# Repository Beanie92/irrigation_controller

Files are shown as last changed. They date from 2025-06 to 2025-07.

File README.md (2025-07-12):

# Hydr8: Irrigation Controller



An ESP32-C6 based irrigation controller with web interface, manual controls, and flexible scheduling.

## Features

- **WiFi & Web UI**: Configure and control the system from any web browser.
- **Manual Control**: Use the physical rotary encoder for on-the-spot adjustments.
- **Flexible Scheduling**: Set up to three different irrigation cycles (A, B, C) with custom start times, zone durations, and active days.
- **NTP Time Sync**: Automatically keeps time updated from the internet.
- **IPS Display**: A clear color display shows system status and menus with auto dimming.
- **8-Channel Control**: Manages a pump and up to seven irrigation zones.
- **Fully Offline Mode**: Operates completely without a WiFi connection, with all features accessible via the device interface.

## Screenshots

### Web Interface



### On-Device UI

Screenshot from 2025-06-29 21-27-22

## Hardware

- **CAD Files**: [View on OnShape](https://cad.onshape.com/documents/08bfc36dcbbf2398b4b87e4d/w/2dae12507b7940b517cf4320/e/530747a0889b15aeda69d576)
- **Electronics** (sourced from [robotics.org.za](https://www.robotics.org.za/)):
  - FireBeetle 2 ESP32-C6 IoT Development Board
  - Wave 2 Inch IPS Display 320x240 SPI ST7789
  - Rotary Encoder Module - Breadboard Ready
  - 4 x 2-Channel Relay Module Opto Isolated 3.3V & 5V Logic 10A Load
  - Battery LiPo 5000mAh 3.7V
  - WCS1500 Hall 35A Current Sensor

## Firmware

The firmware is built using the Arduino framework for the ESP32. It includes a web server, a full UI for the display, and handles all the logic for scheduling and manual control.

For detailed instructions on how to set up the development environment, configure the firmware, and upload it to the ESP32, please see the [firmware README](./firmware/README.md).

## Future Work

- **Smarter Current Monitoring**: Implement logic to use the WCS1800 current sensor to detect pump failures, dry running, or other anomalies, and provide alerts or shut down the system automatically.

## Gallery

Build before the mess of wires:



Build after the mess of wires:



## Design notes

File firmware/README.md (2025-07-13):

# Irrigation Controller Firmware

ESP32-C6 based irrigation controller with WiFi connectivity and NTP time synchronization.

## Features

- **WiFi Connectivity**: Automatic connection to saved WiFi networks
- **NTP Time Synchronization**: Automatic time sync from internet time servers
- **Web Server Interface**: Configure settings, view status, and control zones/cycles via a web browser.
- **Manual Zone Control**: Control individual irrigation zones via rotary encoder interface or web UI.
- **Cycle Scheduling**: Three programmable irrigation schedules (A, B, C) configurable via device UI or web UI.
- **TFT Display**: 240x320 color display with intuitive menu system.
- **Relay Control**: 8-channel relay control (1 pump + 7 zones).
- **Fully Offline Mode**: Operates completely without a WiFi connection, with all features accessible via the device interface.

## Hardware Requirements

- ESP32-C6 development board (DFRobot Beetle ESP32-C6)
- ST7789 240x320 TFT display
- KY-040 rotary encoder with button
- 4 x 2-channel relay module
- Power supply suitable for your relay/pump requirements

## Pin Configuration

### Display (ST7789)
- DC: Pin 2
- CS: Pin 6
- RST: Pin 3

### Rotary Encoder (KY-040)
- CLK: Pin 4
- DT: Pin 7
- SW: Pin 16

### Relays
- Relay 0 (Pump): Pin 19
- Relay 1 (Zone 1): Pin 20
- Relay 2 (Zone 2): Pin 17
- Relay 3 (Zone 3): Pin 18
- Relay 4 (Zone 4): Pin 15
- Relay 5 (Zone 5): Pin 21
- Relay 6 (Zone 6): Pin 8
- Relay 7 (Zone 7): Pin 14

### Current Sensor
-  Anlog Read: Pin 1

## WiFi Setup

The system uses **WiFiManager** with a captive portal for easy WiFi configuration - **WiFi setup is completely optional!**

### Optional WiFi Setup (User-Controlled)

WiFi is now configured through the Settings menu - the system boots directly to the main menu without any WiFi delays.

1. **Navigate to Settings** from the main menu using the rotary encoder
2. **Select "WiFi Setup"** to start the configuration process
3. **The device creates a hotspot**:
   - **Network Name**: `IrrigationController`
   - **Password**: `irrigation123`
4. **Connect your phone/laptop** to the `IrrigationController` network
5. **Open a web browser** - you'll be automatically redirected to the config page
   - If not redirected, go to: `192.168.4.1`
6. **Select your WiFi network** from the list and enter your password
7. **Click Save** - the device will connect to your WiFi and sync time

### Status Display

The device display will show:
- **"WiFi Setup - Connecting..."** when attempting connection
- **"WiFi Setup Required"** with step-by-step instructions when captive portal is active
- **"WiFi Connected!"** with network details when successful
- **"WiFi Setup Timed Out"** if configuration takes too long (3 minutes)

### Reconfiguring WiFi

To change WiFi settings:
1. Use the "WiFi Reset" option in the Settings menu on the device.
2. The captive portal will automatically start again on the next "WiFi Setup" attempt or if the device cannot connect to a previously saved network.

### Troubleshooting WiFi

- **Portal not appearing**: Ensure you're connected to `IrrigationController` network
- **Can't connect to portal**: Try browsing to `192.168.4.1` manually
- **WiFi keeps failing**: Check 2.4GHz network (ESP32 doesn't support 5GHz)
- **Timeout issues**: Portal times out after 3 minutes - restart device to try again

## Time Configuration

The system automatically synchronizes time with NTP servers when WiFi is connected:

- **NTP Server**: pool.ntp.org
- **Timezone**: GMT+2 (Botswana/South Africa)
- **Sync Interval**: Every hour
- **Fallback**: Software clock when WiFi unavailable

To change timezone, modify these values in the code:
```cpp
const long gmtOffset_sec = 7200;     // GMT+2 (adjust as needed)
const int daylightOffset_sec = 0;    // Daylight saving offset
```

## Web Server Interface

Once the ESP32 is connected to your WiFi network, you can access the web interface by navigating to its IP address in a web browser. The IP address is displayed on the device's screen after a successful WiFi connection and also printed to the Serial Monitor.

The web interface allows you to:
- View current system time and relay (zone) statuses.
- Manually set the system date and time.
- Manually start individual zones for a specified duration.
- Stop all currently running irrigation activity.
- View and configure all three irrigation cycles (A, B, C):
    - Enable/disable cycles.
    - Set start time (hour, minute).
    - Set inter-zone delay.
    - Select active days of the week.
    - Configure run durations for each of the 7 zones.
- Manually start a configured cycle.

## Menu System

### Main Menu
- **Manual Run**: Start individual zones manually
- **Settings**: Access system configuration options
- **Set Cycle Start**: Configure cycle start times
- **Cycle A/B/C**: Configure automated irrigation cycles

### Settings Submenu
- **WiFi Setup**: Launch captive portal for WiFi configuration
- **Set Time Manually**: Configure date/time manually (when NTP unavailable)
- **WiFi Reset**: Clear saved WiFi credentials
- **System Info**: View hardware and network status
- **Back to Main Menu**: Return to main menu

### Navigation
- **Rotate Encoder**: Navigate through options
- **Press Button**: Select/confirm option
- **Long Press**: Cancel/return to previous menu

## Programming Irrigation Schedules

Each cycle (A, B, C) can be configured with:
- **Zone Durations**: Individual run times for each zone (0-120 minutes)
- **Inter-zone Delay**: Pause between zones (0-30 minutes)
- **Start Time**: When the cycle should begin
- **Active Days**: Which days of the week to run

## Troubleshooting

### WiFi Connection Issues
1. Check SSID and password are correct
2. Ensure 2.4GHz network (ESP32 doesn't support 5GHz)
3. Check signal strength in installation location
4. Monitor serial output for connection status

### Time Sync Issues
1. Verify WiFi connection is working
2. Check internet connectivity
3. Firewall may be blocking NTP (port 123)
4. Try different NTP server if needed

### Display Issues
1. Check all display connections
2. Verify power supply voltage
3. Check SPI pin assignments match your hardware

## Development

### Arduino IDE Setup
1. Install ESP32 board package
2. Select "ESP32C6 Dev Module" as board
3. Install required libraries via the Arduino Library Manager:
   - **Adafruit GFX Library**: A dependency for the display driver.
   - **ArduinoJson**: Used for handling JSON data for configuration.
   - **ESPAsyncWebServer**: Powers the web interface. **Note**: This library seems to work reliably with version 3.7.1.
   - **LittleFS**: For file system storage.
   - **WiFiManager** by tzapu: For easy WiFi configuration.

### Web UI Development

The web interface assets (HTML, JavaScript) are located in the `web-ui` directory. This project uses `webpack` to bundle and optimize the assets.

**Prerequisites:**
- [Node.js and npm](https://nodejs.org/en/download/)

**Workflow:**

1.  **Navigate to the UI directory:**
    ```bash
    cd web-ui
    ```

2.  **Install dependencies** (only needs to be done once):
    ```bash
    npm install
    ```

3.  **Make changes** to the source files located in `web-ui/src` and `web-ui/plot.js`.

4.  **Build the web assets:**
    ```bash
    npm run build
    ```
    This command will:
    - Bundle the JavaScript and HTML files.
    - Copy static assets.
    - Create Gzip-compressed versions of the assets (`.gz`).
    - Place all the final files into the `firmware/data` directory.

5.  **Upload to ESP32:**
    - After building, use the **Tools > ESP32 Sketch Data Upload** option in the Arduino IDE. This will upload the contents of the `data` directory to the device's LittleFS filesystem.

The firmware is configured to automatically serve the gzipped assets, which reduces storage space and improves loading times.

### Serial Debug Output
Enable debug output by setting:
```cpp
#define DEBUG_ENABLED true
```

Connect serial monitor at 115200 baud to see detailed system information.

## Safety Notes

- Always verify relay wiring before connecting pumps/valves
- Use appropriate fuses and circuit protection
- Test manual operation before setting up automated cycles
- Ensure adequate power supply for your specific hardware
- Consider using contactors for high-power pumps

## License

This project is open source. Use and modify as needed for your irrigation requirements.

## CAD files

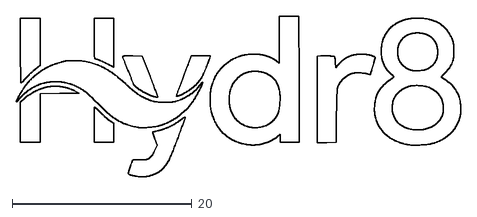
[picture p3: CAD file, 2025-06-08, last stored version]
logo (1).dxf
49.5 x 17.9

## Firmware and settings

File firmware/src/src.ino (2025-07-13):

#include <Arduino.h>
#include "st7789_dma_driver.h" // Replaced DFRobot_GDL.h
#include "styling.h"
#include "CustomCanvas.h"
#include "ui_components.h"
#include "web_server.h" // Include the web server header
#include "wifi_manager.h" // Include the new WiFi manager
#include "config_manager.h" // Include the configuration manager
#include "current_sensor.h" // Include the current sensor header
#include "battery.h" // Include the battery header
#include "logo.h"
#include <LittleFS.h>

// -----------------------------------------------------------------------------
//                           DEBUG CONFIGURATION
// -----------------------------------------------------------------------------
#define DEBUG_ENABLED false  // Set to false to disable all debug logging

#if DEBUG_ENABLED
  #define DEBUG_PRINT(x) Serial.print(x)
  #define DEBUG_PRINTLN(x) Serial.println(x)
  #define DEBUG_PRINTF(format, ...) Serial.printf(format, ##__VA_ARGS__)
#else
  #define DEBUG_PRINT(x)
  #define DEBUG_PRINTLN(x)
  #define DEBUG_PRINTF(format, ...)
#endif

// -----------------------------------------------------------------------------
//                    Rotary Encoder Inputs / Global Variables
// -----------------------------------------------------------------------------
static const int pinA   = 4;   // KY-040 CLK
static const int pinB   = 7;   // KY-040 DT
static const int button = 16;  // KY-040 SW (with internal pull-up)

volatile long encoderValue = 0;
volatile bool encoderMoved = false;
volatile bool encoder_button_pressed = false;

// For button software debounce:
unsigned long lastButtonPressTime = 0;
const unsigned long buttonDebounce = 200; // milliseconds

// -----------------------------------------------------------------------------
//                        Relay Pins / Configuration
// -----------------------------------------------------------------------------
const int NUM_RELAYS = 8; // Made non-static for web_server.h extern
// Relay 0 is dedicated to the borehole pump;
// Relays 1..7 are the irrigation zones.
static const int relayPins[NUM_RELAYS] = {19, 20, 17, 18, 15, 21, 8, 14}; 
bool relayStates[NUM_RELAYS] = {false, false, false, false, false, false, false, false};

static const int PUMP_IDX = 0;   // borehole pump
// ZONE_COUNT is now defined in ui_components.h

// -----------------------------------------------------------------------------
//                           Display Pins / Driver
// -----------------------------------------------------------------------------
#define TFT_DC   2
#define TFT_CS   6
#define TFT_RST  3
#define TFT_BL   5 // Backlight control pin for dimming

CustomCanvas canvas(320, 240);

// Relay labels (index 0 is the pump)
const char* relayLabels[NUM_RELAYS] = {
  "Pump (auto)", // index 0; not displayed in manual-run menu
};

// -----------------------------------------------------------------------------
//                           Screen Dimming
// -----------------------------------------------------------------------------
unsigned long lastActivityTime = 0;
const unsigned long inactivityTimeout = 30000; // 30 seconds
bool isScreenDimmed = false;
volatile bool uiDirty = true; // Flag to trigger UI redraw

// -----------------------------------------------------------------------------
//                        Battery Level
// -----------------------------------------------------------------------------
int batteryLevel = 100; // Default to 100 on boot

// -----------------------------------------------------------------------------
//                        Current Sensing Pin / Configuration
// -----------------------------------------------------------------------------
// Current sensor is now handled in current_sensor.cpp


// -----------------------------------------------------------------------------
//                           Menu and Cycle States
// -----------------------------------------------------------------------------
// ActiveOperationType is now defined in ui_components.h

enum UIState {
  STATE_BOOTING,
  STATE_MAIN_MENU,
  STATE_MANUAL_RUN,
  STATE_CYCLES_MENU,
  STATE_CYCLE_A_MENU,
  STATE_CYCLE_B_MENU,
  STATE_CYCLE_C_MENU,
  STATE_SETTINGS,
  STATE_SET_SYSTEM_TIME,
  STATE_WIFI_SETUP_LAUNCHER, // Renamed from STATE_WIFI_SETUP
  STATE_WIFI_RESET,
  STATE_SYSTEM_INFO,
  STATE_RESTART_DEVICE,
  STATE_PROG_A,
  STATE_PROG_B,
  STATE_PROG_C,
  STATE_RUNNING_ZONE,
  STATE_CYCLE_RUNNING,
  STATE_TEST_MODE
};

UIState currentState = STATE_BOOTING;
const int UI_STATE_STACK_SIZE = 10;
UIState uiStateStack[UI_STATE_STACK_SIZE];
int uiStateStackPtr = -1;
ActiveOperationType currentOperation = OP_NONE; // Track what kind of operation is active

// Main Menu Items
static const int MAIN_MENU_ITEMS = 4; 
const char* mainMenuLabels[MAIN_MENU_ITEMS] = {
  "Manual Run",
  "Cycles", // New submenu
  "Test Mode",
  "Settings"
};
int selectedMainMenuIndex = 0; 

// Cycles Menu Items (lists Cycle A, B, C)
static const int CYCLES_MENU_ITEMS = 3; // A, B, C
const char* cyclesMenuLabels[CYCLES_MENU_ITEMS] = {
  "Cycle A",
  "Cycle B",
  "Cycle C"
};
int selectedCyclesMenuIndex = 0;

// Individual Cycle Sub-Menu Items (Run Now, Configure)
static const int CYCLE_SUB_MENU_ITEMS = 2; // Run Now, Configure
const char* cycleSubMenuLabels[CYCLE_SUB_MENU_ITEMS] = {
  "Run Now",
  "Configure"
};
int selectedCycleSubMenuIndex = 0;
ScrollableList cycleSubMenuScrollList;

// Settings Menu Items
static const int SETTINGS_MENU_ITEMS = 5;
const char* settingsMenuLabels[SETTINGS_MENU_ITEMS] = {
  "WiFi Setup",
  "Set Time Manually",
  "WiFi Reset",
  "System Info",
  "Restart Device"
};
int selectedSettingsMenuIndex = 0;
ScrollableList settingsMenuScrollList;

// WiFi Setup Launcher Menu Items
static const int WIFI_SETUP_LAUNCHER_MENU_ITEMS = 2;
const char* wifiSetupLauncherMenuLabels[WIFI_SETUP_LAUNCHER_MENU_ITEMS] = {
  "Start WiFi Portal",
  "Back"
};
int selectedWiFiSetupLauncherIndex = 0;
ScrollableList wifiSetupLauncherScrollList;

// Manual Run zone index: 0..6 => zone = index+1
int selectedManualZoneIndex = 0;
// Made non-static to be accessible from web_server.cpp
int selectedManualDuration = 5;  // Default 5 minutes 
bool selectingDuration = false;  // Whether we're selecting duration or zone
ScrollableList manualRunScrollList;
const char* zoneNamePointers[ZONE_COUNT]; // Array of pointers for scrollable list

// Cycle Config zone selection
char cycleZoneDisplayStrings[ZONE_COUNT][50];
const char* cycleZoneDisplayPointers[ZONE_COUNT];
int selectedCycleZoneIndex = 0; // Used by all program config screens
bool editingCycleField = false; // Are we editing a field in the cycle config?

// -----------------------------------------------------------------------------
//                           Zone Timer Variables
// -----------------------------------------------------------------------------
unsigned long zoneStartTime = 0;        // When current zone started
unsigned long zoneDuration = 0;         // Duration for current zone in milliseconds
int currentRunningZone = -1;            // Which zone is currently running (-1 = none)
bool isTimedRun = false;                 // Whether this is a timed run or manual indefinite run
int currentRunningCycle = -1;         // Which cycle is currently running (-1 = none, 0=A, 1=B, 2=C)
int currentCycleZoneIndex = -1;       // Current zone index within a running cycle
unsigned long cycleZoneStartTime = 0; // When current cycle zone started
unsigned long cycleInterZoneDelayStartTime = 0; // When inter-zone delay started
bool inInterZoneDelay = false;          // Flag for inter-zone delay

// -----------------------------------------------------------------------------
//                           Test Mode Variables
// -----------------------------------------------------------------------------
bool testModeActive = false;
int currentTestRelay = 0;           // 0-7: 0=pump, 1-7=zones
unsigned long testModeStartTime = 0;
const unsigned long TEST_INTERVAL = 5000; // 5 seconds per relay

// -----------------------------------------------------------------------------
//                  Time-Keeping (Software Simulation)
// -----------------------------------------------------------------------------
SystemDateTime currentDateTime = {2023, 1, 1, 8, 0, 0}; // Example start date/time
unsigned long lastSecondUpdate = 0; // track millis() to increment seconds

void incrementOneSecond() {
  // Very simplistic approach: just add 1 second, then handle minute/hour/day wrap
  currentDateTime.second++;
  if (currentDateTime.second >= 60) {
    currentDateTime.second = 0;
    currentDateTime.minute++;
    if (currentDateTime.minute >= 60) {
      currentDateTime.minute = 0;
      currentDateTime.hour++;
      if (currentDateTime.hour >= 24) {
        currentDateTime.hour = 0;
        currentDateTime.day++;
        // Very naive day wrap (assumes 30 days). In real code, handle months properly.
        if (currentDateTime.day > 30) {
          currentDateTime.day = 1;
          currentDateTime.month++;
          if (currentDateTime.month > 12) {
            currentDateTime.month = 1;
            currentDateTime.year++;
          }
        }
      }
    }
  }
}

// -----------------------------------------------------------------------------
//                 Cycle Config
// -----------------------------------------------------------------------------
// TimeOfDay and CycleConfig structs are now defined in ui_components.h

CycleConfig* cycles[] = {&systemConfig.cycles[0], &systemConfig.cycles[1], &systemConfig.cycles[2]};
const int NUM_CYCLES = 3; // Made non-static for web_server.h extern

// -----------------------------------------------------------------------------
//                Sub-indexes and helpers for editing fields
// -----------------------------------------------------------------------------
static int timeEditFieldIndex = 0;    // 0=year,1=month,2=day,3=hour,4=minute,5=second
static bool editingTimeField = false;
static int cycleEditFieldIndex = 0; // 0=enabled, 1=hour, 2=minute, 3=interZoneDelay, 4-10=days, 11-17=zone durations
static int zoneEditScrollOffset = 0; // For scrolling through zones in cycle config

// Ranges for system time fields (simple example)
#define MIN_YEAR  2020
#define MAX_YEAR  2050


// Global instance for main menu
ScrollableList mainMenuScrollList;
ScrollableList cyclesMenuScrollList;
ScrollableList cycleZonesScrollList; // For zone durations in cycle config
ScrollableList setTimeScrollList;

// -----------------------------------------------------------------------------
//                           Forward Declarations
// -----------------------------------------------------------------------------
void updateScreen();
void render();
void isrPinA();
void handleEncoderMovement();
void handleButtonPress();

void drawLogo();
void drawMainMenu();
void drawCyclesMenu();
void drawCycleSubMenu(const char* label);
void navigateTo(UIState newState, bool isNavigatingBack = false);
void goBack();

void updateSoftwareClock();
DayOfWeek getCurrentDayOfWeek();

// Manual Run
void drawManualRunMenu();
void drawRunningZoneMenu();
void startManualZone(int zoneIdx);
void stopAllActivity(); // Renamed from stopZone

// Set System Time
void drawSetSystemTimeMenu();
void handleSetSystemTimeEncoder(long diff);
void handleSetSystemTimeButton();

// Program A/B/C
void drawCycleConfigMenu(const char* label, CycleConfig& cfg);
void handleCycleEditEncoder(long diff, CycleConfig &cfg, const char* progLabel);
void handleCycleEditButton(CycleConfig &cfg, UIState thisState, const char* progLabel);
void startCycleRun(int cycleIndex, ActiveOperationType type);
void updateCycleRun();
void drawCycleRunningMenu();

// Settings menu functions
void drawSettingsMenu();
void drawWiFiResetMenu();
void drawSystemInfoMenu();
void drawWiFiSetupLauncherMenu(); // Renamed from drawWiFiSetupMenu
void drawRestartDeviceMenu();

// Test Mode functions
void startTestMode();
void updateTestMode();
void drawTestModeMenu();
void stopTestMode();

// -----------------------------------------------------------------------------
//                              RELAY CONTROL
// -----------------------------------------------------------------------------
bool isAnyZoneActive() {
  for (int i = 1; i < NUM_RELAYS; i++) {
    if (relayStates[i]) {
      return true;
    }
  }
  return false;
}

void setPumpState(bool on) {
  if (on) {
    // Only turn the pump on if at least one zone is active.
    if (isAnyZoneActive()) {
      if (!relayStates[PUMP_IDX]) {
        DEBUG_PRINTF("Activating pump relay (pin %d)\n", relayPins[PUMP_IDX]);
        relayStates[PUMP_IDX] = true;
        digitalWrite(relayPins[PUMP_IDX], HIGH);
      }
    } else {
      DEBUG_PRINTLN("PUMP SAFETY: Pump activation prevented. No zones are active.");
      // Ensure pump is off if we get here, just in case.
      if (relayStates[PUMP_IDX]) {
        relayStates[PUMP_IDX] = false;
        digitalWrite(relayPins[PUMP_IDX], LOW);
      }
    }
  } else {
    // Turn the pump off.
    if (relayStates[PUMP_IDX]) {
      DEBUG_PRINTF("Deactivating pump on pin %d\n", relayPins[PUMP_IDX]);
      relayStates[PUMP_IDX] = false;
      digitalWrite(relayPins[PUMP_IDX], LOW);
    }
  }
}
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
void loop() {
  // --------------------- SAFETY CHECK ---------------------
  // Ensure the pump is never running if no zones are active.
  // This is a failsafe in case of a logic error elsewhere.
  if (relayStates[PUMP_IDX] && !isAnyZoneActive()) {
    DEBUG_PRINTLN("!!! PUMP SAFETY ALERT !!! Pump was on without an active zone. Forcing OFF.");
    setPumpState(false);
  }
  // --------------------------------------------------------

  // Handle WiFi and NTP updates
  wifi_manager_handle();

  // --- DEBUG: Read and print current sensor value ---
  static unsigned long lastCurrentRead = 0;
  if (millis() - lastCurrentRead > 2000) { // Read every 2 seconds
    float current = read_wcs1800_current();
    DEBUG_PRINTF("[CURRENT] Reading: %.5f A\n", current);
    lastCurrentRead = millis();
  }
  // ----------------------------------------------------

  // Update the current history
  update_current_history();

  // --- Read battery level ---
  static unsigned long lastBatteryRead = 0;
  if (millis() - lastBatteryRead > 5000) { // Read every 5 seconds
    batteryLevel = read_battery_level();
    DEBUG_PRINTF("[BATTERY] Level: %d%%\n", batteryLevel);
    lastBatteryRead = millis();
    uiDirty = true; // Redraw header with new level
  }
  // ----------------------------------------------------
  
  if (encoder_button_pressed && currentState == STATE_BOOTING) {
    wifi_manager_cancel_connection();
    encoder_button_pressed = false; // Reset flag
  }

  if (wifi_manager_is_connecting() == false && currentState == STATE_BOOTING) {
    navigateTo(STATE_MAIN_MENU);
  }

  // Update time - use NTP if available, otherwise software clock
  if (wifi_manager_is_time_synced()) {
    wifi_manager_update_system_time(currentDateTime); // Update our time structure from system time
  } else {
    updateSoftwareClock(); // Fallback to software clock
  }
  
  handleEncoderMovement();
  handleButtonPress();

  // Render the UI if needed
  render();

  // Handle screen dimming
  if (!isScreenDimmed && (millis() - lastActivityTime > inactivityTimeout)) {
    isScreenDimmed = true;
    st7789_set_backlight(false); // Dim the screen using the driver
    DEBUG_PRINTLN("Screen dimmed due to inactivity.");
  }

  // Check for scheduled cycles if no other operation is active
  if (currentOperation == OP_NONE) {
    DayOfWeek currentDay = getCurrentDayOfWeek();
    for (int i = 0; i < NUM_CYCLES; i++) {
      CycleConfig* cfg = cycles[i];
      if (cfg->enabled && (cfg->daysActive & currentDay) &&
          currentDateTime.hour == cfg->startTime.hour &&
          currentDateTime.minute == cfg->startTime.minute &&
          currentDateTime.second == 0) { // Trigger at the start of the minute
        DEBUG_PRINTF("Scheduled cycle %s triggered!\n", cfg->name);
        startCycleRun(i, OP_SCHEDULED_CYCLE);
        break; // Only one cycle can start per second
      }
    }
  }

  // Additional logic for running states if needed
  if (currentState == STATE_RUNNING_ZONE) {
    static unsigned long lastDisplayUpdate = 0;
    if (millis() - lastDisplayUpdate > 5000) {
      lastDisplayUpdate = millis();
      uiDirty = true;
    }
    
    if (isTimedRun && zoneDuration > 0) {
      unsigned long elapsed = millis() - zoneStartTime;
      if (elapsed >= zoneDuration) {
        DEBUG_PRINTLN("Zone timer expired - stopping zone");
        stopAllActivity();
        navigateTo(STATE_MAIN_MENU);
      }
    }
  } else if (currentState == STATE_CYCLE_RUNNING) {
    updateCycleRun();
  } else if (currentState == STATE_TEST_MODE && testModeActive) {
    updateTestMode();
  }
}

// -----------------------------------------------------------------------------
//                        INTERRUPT SERVICE ROUTINE
// -----------------------------------------------------------------------------
void IRAM_ATTR isrPinA() {
  bool A = digitalRead(pinA);
  bool B = digitalRead(pinB);
  if (A == B) {
    encoderValue = encoderValue - 1;
  } else {
    encoderValue = encoderValue + 1;
  }
  encoderMoved = true;
  uiDirty = true;
}

// -----------------------------------------------------------------------------
//                         ENCODER & BUTTON HANDLERS
// -----------------------------------------------------------------------------
static long lastEncoderPosition = 0;
void handleEncoderMovement() {
  if (!encoderMoved) return;

  noInterrupts();
  long newVal = encoderValue;
  encoderMoved = false;
  interrupts();

  long diff = newVal - lastEncoderPosition;
  lastEncoderPosition = newVal;
  if (diff == 0) return;

  lastActivityTime = millis();
  if (isScreenDimmed) {
    st7789_set_backlight(true); // Full brightness
    isScreenDimmed = false;
    uiDirty = true; // Redraw the screen
    DEBUG_PRINTLN("Screen woken up by encoder movement.");
    return; // Ignore the first input
  }
  uiDirty = true;

  DEBUG_PRINTF("Encoder moved: diff=%ld, state=%d\n", diff, currentState);

  switch (currentState) {
    case STATE_MAIN_MENU:
      handleScrollableListInput(mainMenuScrollList, diff);
      break;

    case STATE_CYCLES_MENU:
      handleScrollableListInput(cyclesMenuScrollList, diff);
      break;

    case STATE_CYCLE_A_MENU:
    case STATE_CYCLE_B_MENU:
    case STATE_CYCLE_C_MENU:
      handleScrollableListInput(cycleSubMenuScrollList, diff);
      break;

    case STATE_MANUAL_RUN:
      if (selectingDuration) {
        selectedManualDuration += diff;
        if (selectedManualDuration < 1) selectedManualDuration = 120;
        if (selectedManualDuration > 120) selectedManualDuration = 1;
        DEBUG_PRINTF("Manual run duration selection: %d minutes\n", selectedManualDuration);
      } else {
        handleScrollableListInput(manualRunScrollList, diff);
      }
      break;

    case STATE_SETTINGS:
      handleScrollableListInput(settingsMenuScrollList, diff);
      break;

    case STATE_WIFI_SETUP_LAUNCHER:
      handleScrollableListInput(wifiSetupLauncherScrollList, diff);
      break;

    case STATE_SET_SYSTEM_TIME:
      handleSetSystemTimeEncoder(diff);
      break;

    case STATE_PROG_A:
      handleCycleEditEncoder(diff, systemConfig.cycles[0], "Cycle A");
      break;

    case STATE_PROG_B:
      handleCycleEditEncoder(diff, systemConfig.cycles[1], "Cycle B");
      break;

    case STATE_PROG_C:
      handleCycleEditEncoder(diff, systemConfig.cycles[2], "Cycle C");
      break;

    case STATE_RUNNING_ZONE:
    case STATE_CYCLE_RUNNING:
      DEBUG_PRINTLN("Encoder ignored - zone/cycle is running");
      break;

    default:
      DEBUG_PRINTF("Encoder movement in unknown state: %d\n", currentState);
      break;
  }
}
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

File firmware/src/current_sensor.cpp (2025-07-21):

#include <Arduino.h>
#include "current_sensor.h"
#include <vector>
#include <cstdint>
#include <cmath>

// WCS1800 Current Sensor Configuration for ESP32
const int WCS1800_PIN = 1;       // WCS1800 connected to ESP32 analog pin 1 (ADC1_CH0)

// Using user-provided calibration values
const float SENSITIVITY = 0.0101;   // Sensitivity in V/A from calibration
const float VREF_ZERO_CURRENT = 1.632; // Reference voltage at zero current from calibration (in Volts)

/**
 * @brief Initializes the current sensor pin.
 * On the ESP32, setting the attenuation is good practice for analog inputs.
 * ADC_11db gives a full-range of approx. 0-3.3V.
 */
void setup_current_sensor() {
  analogSetPinAttenuation(WCS1800_PIN, ADC_11db);
}

/**
 * @brief Reads the current from the WCS1800 sensor with averaging.
 * 
 * @return The current in Amperes.
 */
float read_wcs1800_current() {
  const int NUM_SAMPLES = 5;
  float total_voltage_mv = 0;

  for (int i = 0; i < NUM_SAMPLES; i++) {
    total_voltage_mv += analogReadMilliVolts(WCS1800_PIN);
    delay(1); // Small delay for stability
  }

  float average_voltage_mv = total_voltage_mv / NUM_SAMPLES;
  
  // Convert measured millivolts to volts
  float voltage = average_voltage_mv / 1000.0;

  // Calculate the current in Amperes using the provided calibration values
  // Formula: Current = (MeasuredVoltage - VoltageAtZeroCurrent) / Sensitivity
  float current = (voltage - VREF_ZERO_CURRENT) / SENSITIVITY;

  return current;
}

// --- Current History ---
const float COV_THRESHOLD = 0.01f; // 200 mA
const uint64_t MIN_TIME_INTERVAL_US = 900000ULL * 1000; // 15 minutes in microseconds
const size_t MAX_HISTORY_SIZE = 200;
const uint64_t MIN_SAMPLE_INTERVAL_US = 500ULL * 1000; // Minimum time between samples in microseconds

static std::vector<CurrentHistoryEntry> current_history;
static uint64_t last_update_time_us = 0;
static float last_recorded_current = 0.0f;

void update_current_history() {
    static uint64_t last_sample_time_us = 0;
    uint64_t current_time_us = esp_timer_get_time();

    // Enforce a minimum delay between samples
    if (current_time_us - last_sample_time_us < MIN_SAMPLE_INTERVAL_US) {
        return;
    }
    last_sample_time_us = current_time_us;

    float current_now = read_wcs1800_current();

    bool cov_triggered = abs(current_now - last_recorded_current) > COV_THRESHOLD;
    bool time_triggered = (current_time_us - last_update_time_us) > MIN_TIME_INTERVAL_US;

    if (cov_triggered || time_triggered) {
        if (current_history.size() >= MAX_HISTORY_SIZE) {
            current_history.erase(current_history.begin());
        }
        // Store timestamp in milliseconds for downstream processes
        current_history.push_back({current_time_us / 1000, current_now});
        last_update_time_us = current_time_us;
        last_recorded_current = current_now;
    }
}

const std::vector<CurrentHistoryEntry>& get_current_history() {
    return current_history;
}

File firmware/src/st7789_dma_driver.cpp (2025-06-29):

#include "st7789_dma_driver.h"
#include <SPI.h>

// Global pointer to the display object
static Adafruit_ST7789* tft = nullptr;
static int8_t _bl_pin = -1;

// Initialize the display
void st7789_init_display(int8_t dc_pin, int8_t cs_pin, int8_t rst_pin, int8_t bl_pin, SPIClass* spi_bus) {
    if (tft) {
        delete tft;
    }
    tft = new Adafruit_ST7789(spi_bus, cs_pin, dc_pin, rst_pin);
    _bl_pin = bl_pin;

    tft->init(240, 320); // Initialize with ST7789 chip resolution
    tft->setRotation(1); // Set rotation for 320x240 display
    tft->fillScreen(ST77XX_BLACK);

    if (_bl_pin >= 0) {
        pinMode(_bl_pin, OUTPUT);
        digitalWrite(_bl_pin, HIGH); // Turn backlight on
    }
}

// Push the canvas buffer to the display
void st7789_push_canvas(const uint16_t* buffer, int16_t w, int16_t h) {
    if (!tft) return;
    tft->drawRGBBitmap(0, 0, (uint16_t*)buffer, w, h);
}

// Control backlight
void st7789_set_backlight(bool on) {
    if (_bl_pin >= 0) {
        digitalWrite(_bl_pin, on ? HIGH : LOW);
    }
}

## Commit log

2025-06-08 init platformio
    [logo (1).dxf]
2025-06-08 changed pinout for relays
2025-06-08 moved from arduino to esp32 framework
2025-06-16 Feat: Refactor program config with scrollable zone list
    The previous program configuration screen displayed zone durations as a static list, which could not fit all zones on the screen at once.
    This commit refactors the UI to use a generic `ScrollableList` component for displaying and editing zone durations. This improves scalability and user experience.
    Key changes:
    - The `ScrollableList` component is enhanced to support an optional title.
    - The program config screen now uses this component, allowing users to scroll through all zone durations.
    - A new sub-editing mode is implemented: selecting a zone from the list allows the user to directly edit its duration value.
    - State entry logic fo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
    [src.ino]
2025-06-16 Refactor: Introduce ScrollableList class to manage UI menus
    This commit introduces a new `ScrollableList` class to abstract and simplify the user interface menu logic.
    Previously, each menu (Main, Programs, Settings, etc.) had its own set of global variables for the selected index and duplicated code within the main loop to handle encoder input and list navigation.
    The new `ScrollableList` class encapsulates:
    - State management (selected index, scroll offset).
    - Input handling for encoder rotation.
    - A generic `draw()` method to render the menu, replacing multiple specific `draw...Menu()` functions.
2025-06-16 Refactor: Move date/time display to dedicated UI component
    Extracts the `SystemDateTime` struct, `DayOfWeek` enum, and date/time drawing logic from the main `src.ino` file into new `ui_components.h` and `ui_components.cpp` files.
    This change introduces a new `drawDateTimeComponent` function which replaces the previous `drawDateTime` implementation. The new component also displays the current day of the week.
    [src.ino]
2025-06-16 added default back button on all menus
2025-06-16 Refactor: Implement stack-based UI navigation
    Replace the simple `previousState` variable with a UI state stack to manage navigation history. This allows for proper multi-level "back" functionality, which is a more intuitive user experience than the previous single-level system.
    - The `navigateTo()` function now pushes the current state onto the stack when moving forward.
    - The `goBack()` function pops from the stack to return to the actual previous screen.
    - The Manual Run menu now includes an on-screen "Back" item in the scrollable list, making navigation more consistent with other UI elements.
    [src.ino]
2025-06-16 ranamed programs to cycles and removed buggy debug prints
    [src.ino]
2025-06-16 got custom dma spi driver for st7789v working
2025-06-16 fixed incorrect rgb channels
    [st7789_dma_driver.cpp]
2025-06-21 fixed wifi creds persistence
    [src.ino, wifi_manager.cpp]
2025-06-22 moved to adafruit library for screen driver
2025-06-22 fixed zone name bug
    [config_manager.cpp, src.ino, web_server.cpp]
2025-06-28 fixed wifi disconnecting every second boot
    [wifi_manager.cpp]
2025-06-28 fixed interzone pump bug
    [src.ino, web_server.cpp]
2025-06-29 added extra checks to make sure pump is not running when
2025-06-29 removed logos
    [logo (1).dxf]
2025-07-12 basic current monitoring and added wifi and battery inidicators
2025-07-12 added restart device button
2025-07-13 added history to current reading
2025-07-15 used esp timer for longer range of timestamps
2025-07-15 reduced number of current samples
